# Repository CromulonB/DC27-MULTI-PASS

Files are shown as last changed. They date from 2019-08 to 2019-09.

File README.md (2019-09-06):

# DC27-MULTI-PASS
The MULTI PASS badge is running the firmware created by [badge.team](https://github.com/badgeteam/ESP32-Firmware). It is a unified badge platform that supports running apps written in python. Along with that there is a repository of apps written by other users called the [hatchery](https://badge.team/). The MULTI PASS is compatible with apps written for the SHA and HackerHotel badges.

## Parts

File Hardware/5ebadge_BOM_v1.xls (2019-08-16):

Qty per PCB | Type | Device | Value | Package | Parts
1 | ESP module | ESP32WROOM32 | ESP32-WROOM-32D (16MB) | ESP32MOD | IC3 | x
1 | Touch IC | MPR121QR2 | MPR121QR2 | QFN40P300X300X60-20N | U1 | x
1 | Battery charger IC | TP4056 | TP4056 | SOP-8 | IC4
1 | Voltage regulator | AP2114H-3.3TRG1 | AP2114H-3.3TRG1 | SOT233-3 | IC2 | x
1 | USB-Serial IC | CP210X_USB_UART | CP210X_USB_UART | MLP28 | IC1 | x
1 | Battery connector | JST S3B-PH-SM4-TB | JST S3B-PH-SM4-TB | JST-PH3 | X4 | x
3 | NPN transistor | TRANSISTOR_NPNMMBT2222A | MMBT2222A | SOT23-3 | Q3, Q4, Q6 | x
2 | P-channel MOSFET | MOSFET-PCHANNEL | SSM3J356R,LF | SOT23-3 | T1, T3 | x
1 | N-channel MOSFET | MOSFET-NCHANNEL | 2N7002PW | SOT323 | Q5 | x
2 | Tactile switch | SWITCH-MOMENTARY-2SMD | SKQGABE010 | TACTILE-SWITCH-SMD | S1, S2
1 | USB connector | MOLEX-47346-0001 | 10118192-0001LF | MOLEX-47364-0001 | USB1 | x
1 | IO Expansion header | 610X12243021 | NPPC062KFMS-RC | 610X12243021 | X3 | x
1 | Display socket | 24 pos FPC 0.5mm SMD right angle | 68712414022 | 68712414022 | X1 | x
2 | PTC Fuse | PTCSMD | PTC-1206 1A | PTC-1206 | F1, F2 | x
5 | Schottky diode | BAT20JFILM | NSVR0320MW2T1G | SOD-323 | D2, D3, D7, D8, D9 | x
1 | ESD Suppressor | DIODE-SCHOTTKY-PMEG4005EJ | SD05-7 | SOD-323 | D1 | x
1 | Red LED | LED0603 red | ‎150060RS75000‎ | LED-0603 | D5 | x
1 | Yellow LED | LED0603 yellow | ‎150060YS75000 | LED-0603 | D4 | x
1 | Green LED | LED0603 green | ‎150060VS75000 | LED-0603 | D6 | x
1 | Inductor | INDUCTOR1210 47µ | 445-15771-1-ND (https://www.digikey.com/product-detail/en/tdk-corporation/NLFV32T-470K-EF/445-15771-1-ND/4328067) | L1210 | L1 | x
17 | Capacitor | C0603 100n | CL10B104KB8NNNC (https://www.digikey.com/product-detail/en/samsung-electro-mechanics/CL10B104KB8NNNC/1276-1000-1-ND/3889086) | C0603 | C1, C7, C8, C11, C12, C14, C22, C23, C27, C31, C37, C40, C44, C45, C10, C16, C28, C29 | x
11 | Capacitor | C0603 1µ | CL10B105KA8NNNC (https://www.digikey.com/product-detail/en/samsung-electro-mechanics/CL10B105KA8NNNC/1276-1184-1-ND/3889270) | C0603 | C19, C21, C25, C32, C33, C35, C36, C38, C39, C42, C46 | x
11 | Capacitor | C-EUC0805 4.7µ / 16V | CL21A475KOFNNNE (https://www.digikey.com/product-detail/en/samsung-electro-mechanics/CL21A475KOFNNNE/1276-1065-1-ND/3889151) | C0805 | C9, C15, C17, C18, C20, C24, C26, C30, C34, C41, C43 | x
2 | Resistor | 1.2k | ‎ERJ-3GEYJ122V | R0603 | R29, R35 | x
5 | Resistor | 100k | ERJ-3GEYJ104V | R0603 | R1, R6, R20, R31, R36 | x
12 | Resistor | 10k | ERJ-3GEYJ103V | R0603 | R4, R5, R8, R13, R15, R16, R17, R18, R22, R25, R28, R32 | x
1 | Resistor | 0.27? 1/4W | ERJ-8RQFR27V (https://www.digikey.com/product-detail/en/panasonic-electronic-components/ERJ-8RQFR27V/P.27RCT-ND/250349) | R1206 | R30 | x
3 | Resistor | 1k | ERJ-3GEYJ102V | R0603 | R3, R12, R14 | x
2 | Resistor | 220k | ERJ-3GEYJ224V | R0603 | R7, R21 | x
2 | Resistor | 4k7 | ERJ-PA3J472V (https://www.digikey.com/product-detail/en/panasonic-electronic-components/ERJ-PA3J472V/P4.7KBZCT-ND/5036332) | R0603 | R23, R24 | x
1 | Resistor | 2.7? | ERJ-3GEYJ2R7V (https://www.digikey.com/product-detail/en/panasonic-electronic-components/ERJ-3GEYJ2R7V/P2.7GCT-ND/282415) | R0603 | R19 | x
1 | Resistor | 75k 1% | RMCF0603FT75K0 | R0603 | R37 | x
1 | Micro SD socket | 2908-05WB-MG | 2908-05WB-MG | MICRO-SD-SOCKET-PP | X2 | x
13 | Resistor | R0603 | ERJ-3EKF3000V (https://www.digikey.com/product-detail/en/panasonic-electronic-components/ERJ-3EKF3000V/P300HCT-ND/1746756) | R0603 | R2, R9, R10, R11, R27, R33, R34, R38, R39, R40, R41, R42, R43 | x
1 | MCU | ATMEGA48-20AU | ATMEGA48-20AU | QFP80P900X900X120-32N | U2 | x
2 | JS Slide Switch | slide switch | JS202011SCQN | SW_JS202011SCQN | S3, S4 | x
8 | Topled Yellow Rev.Gul | LED | LY T77K-K2M1-26 | LED_LYT77K-K2M1-26-Z | DY1, DY2, DY3, DY4, DY5, DY6, DY7, DY8 | x
3 | Topled Red Rev.Gul | LED | LS T77K-K1L2-1 | LS T77K-K1L2-1 | DB1, DB2, DB3 | x
126

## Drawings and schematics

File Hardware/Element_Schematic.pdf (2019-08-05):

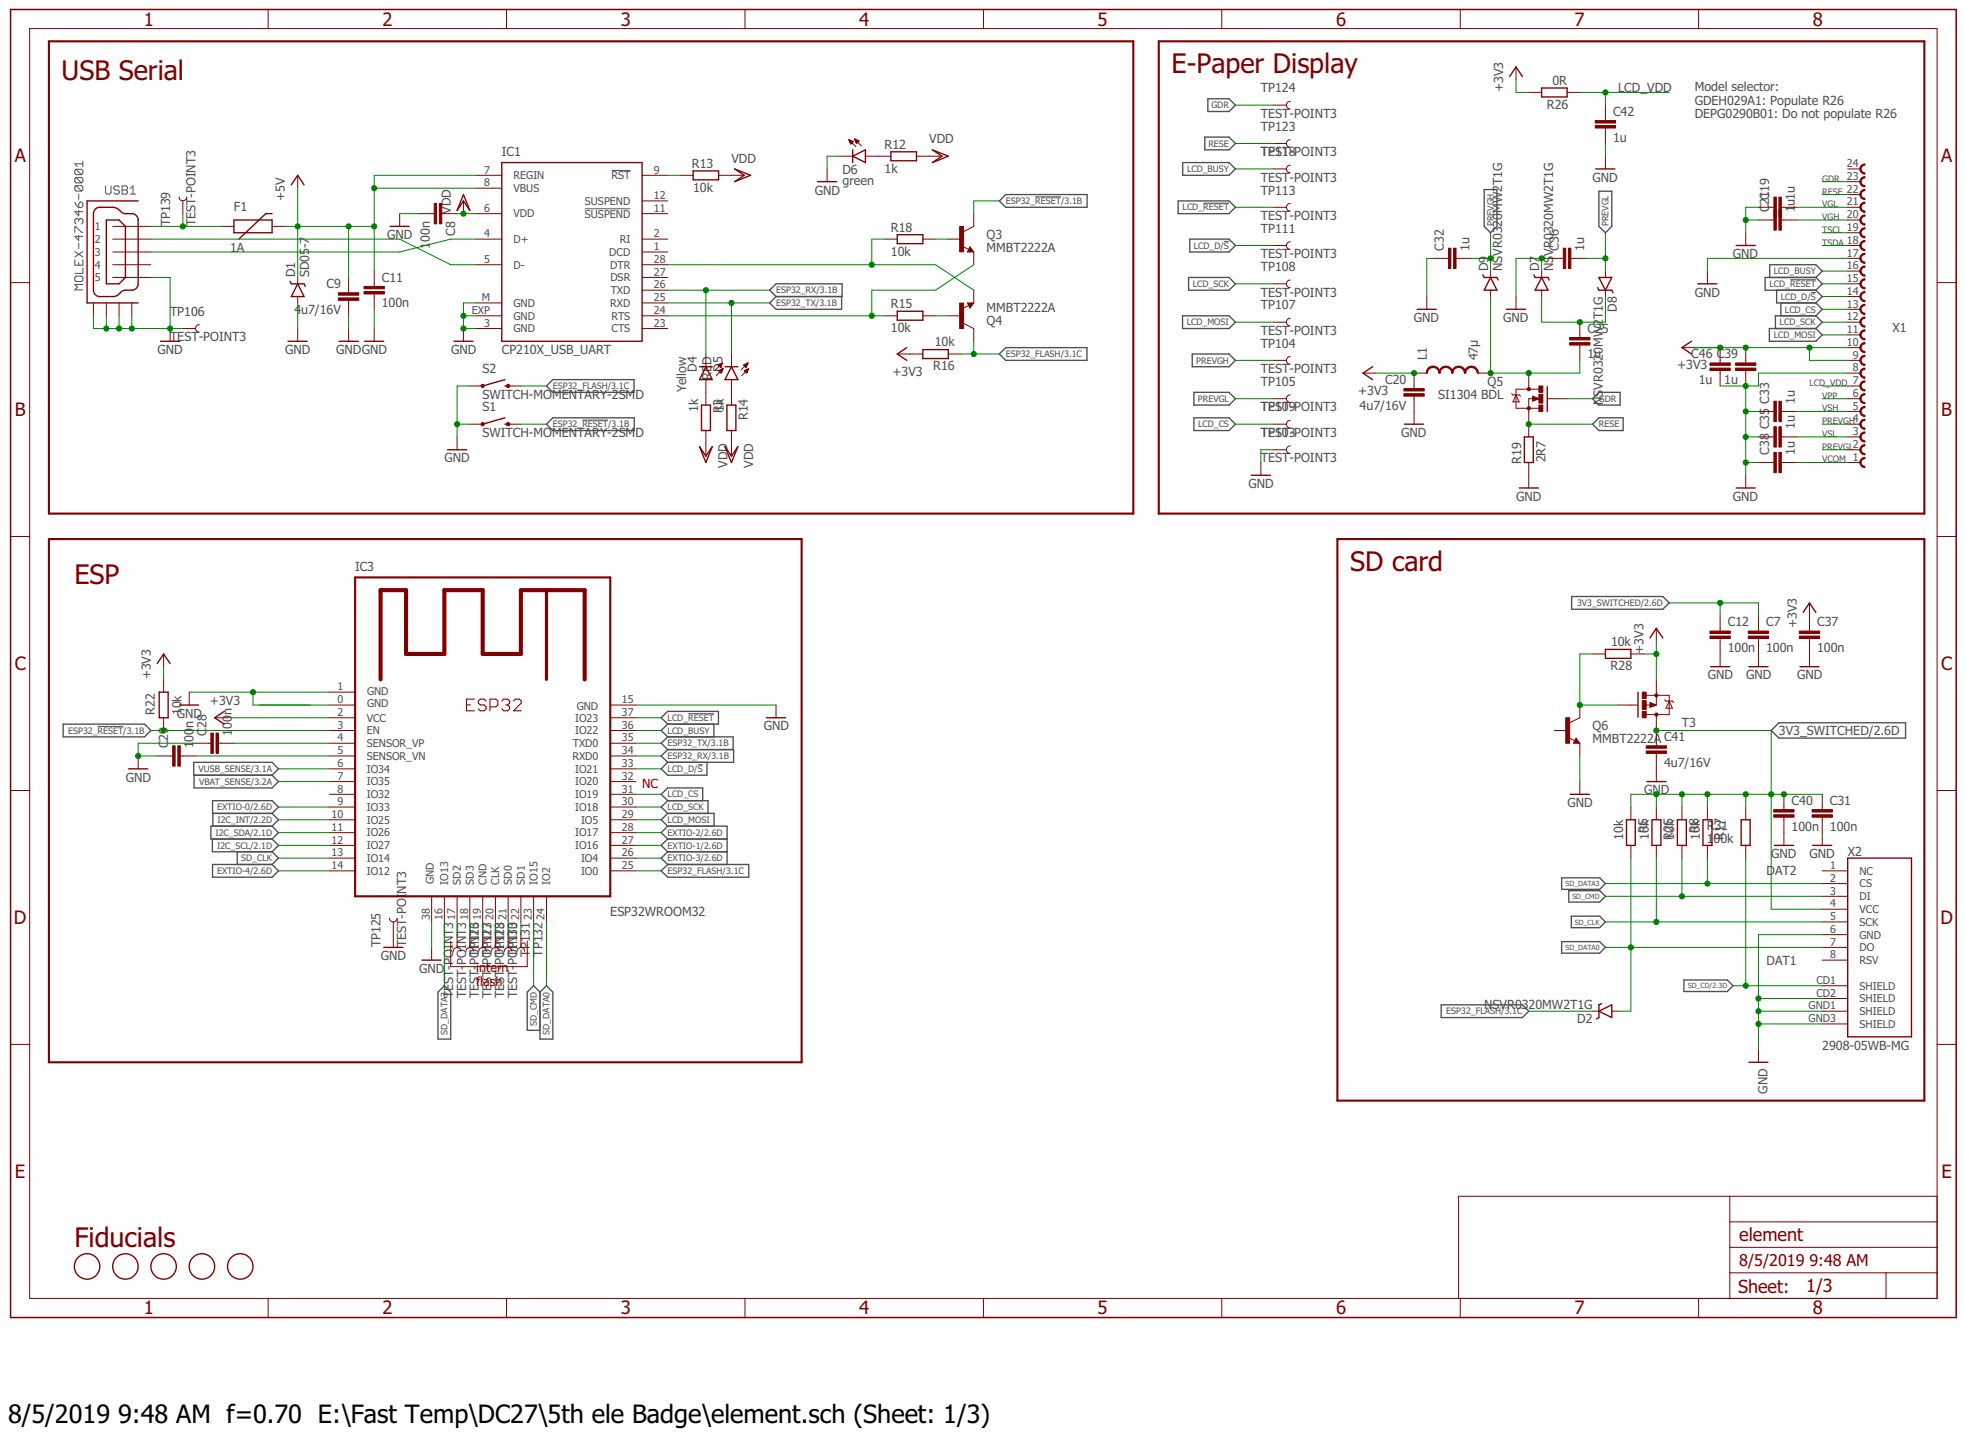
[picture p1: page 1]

TEST-POINT3 TEST-POINT3 TEST-POINT3 TEST-POINT3 TEST-POINT3 TEST-POINT3 TEST-POINT3 TEST-POINT3 TEST-POINT3 TEST-POINT3 TEST-POINT3 GND

Model selector: GDEH029A1: Populate R26 DEPG0290B01: Do not populate R26

TEST-POINT3 TEST-POINT3 TEST-POINT3 TEST-POINT3 TEST-POINT3 TEST-POINT3 TEST-POINT3 GND

8/5/2019 9:48 AM f=0.70 E:\Fast Temp\DC27\5th ele Badge\element.sch (Sheet: 1/3)

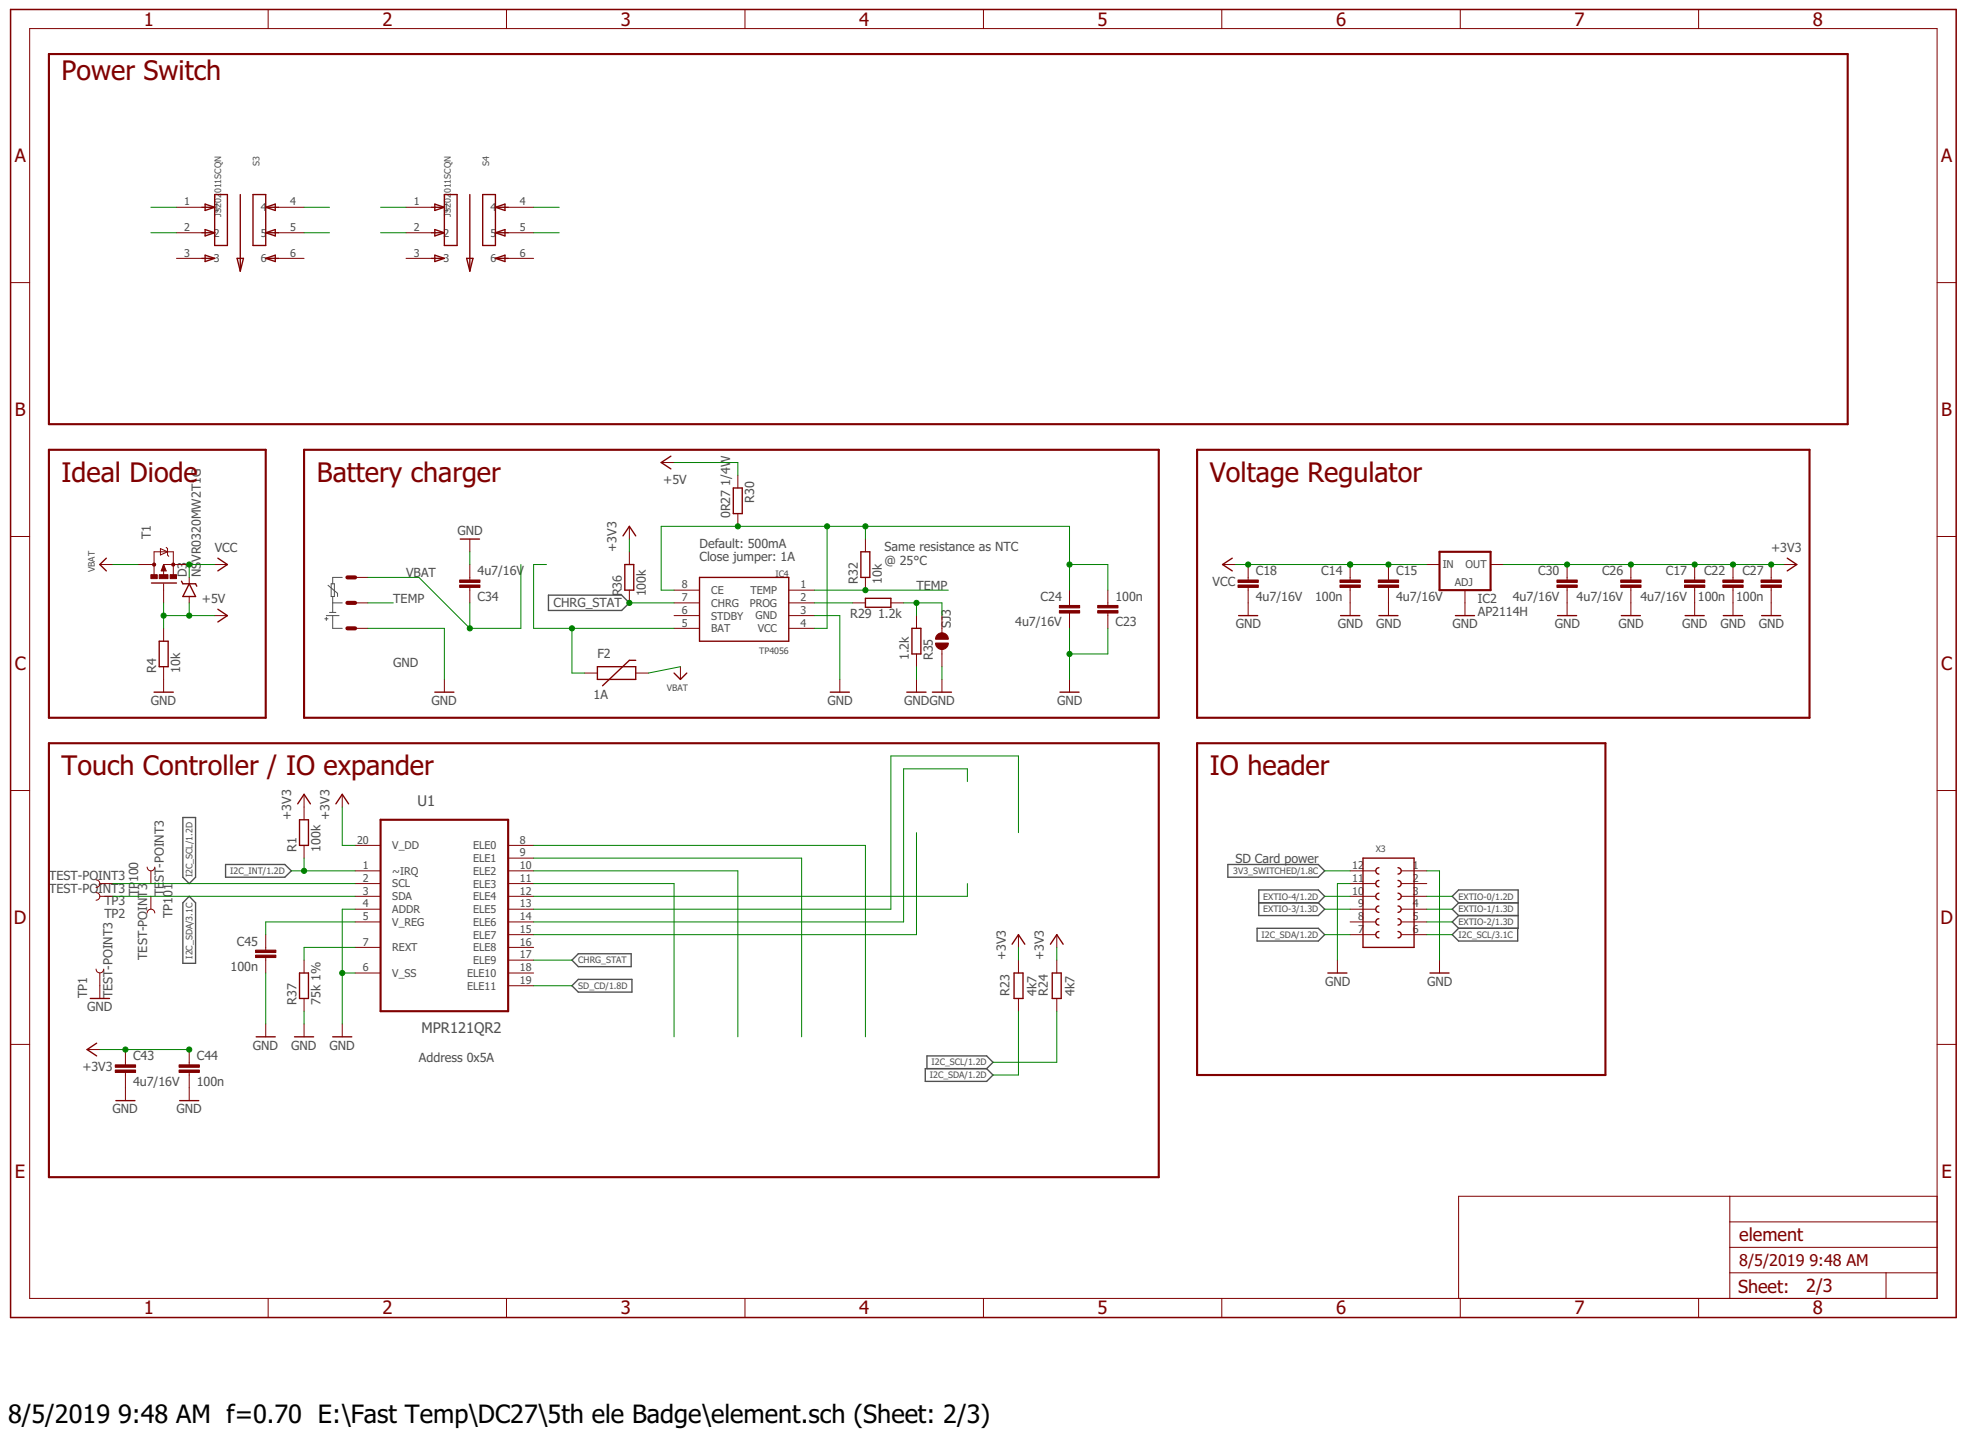
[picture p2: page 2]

Same resistance as NTC @ 25°C

11 ELE4

13 ELE6

8/5/2019 9:48 AM f=0.70 E:\Fast Temp\DC27\5th ele Badge\element.sch (Sheet: 2/3)

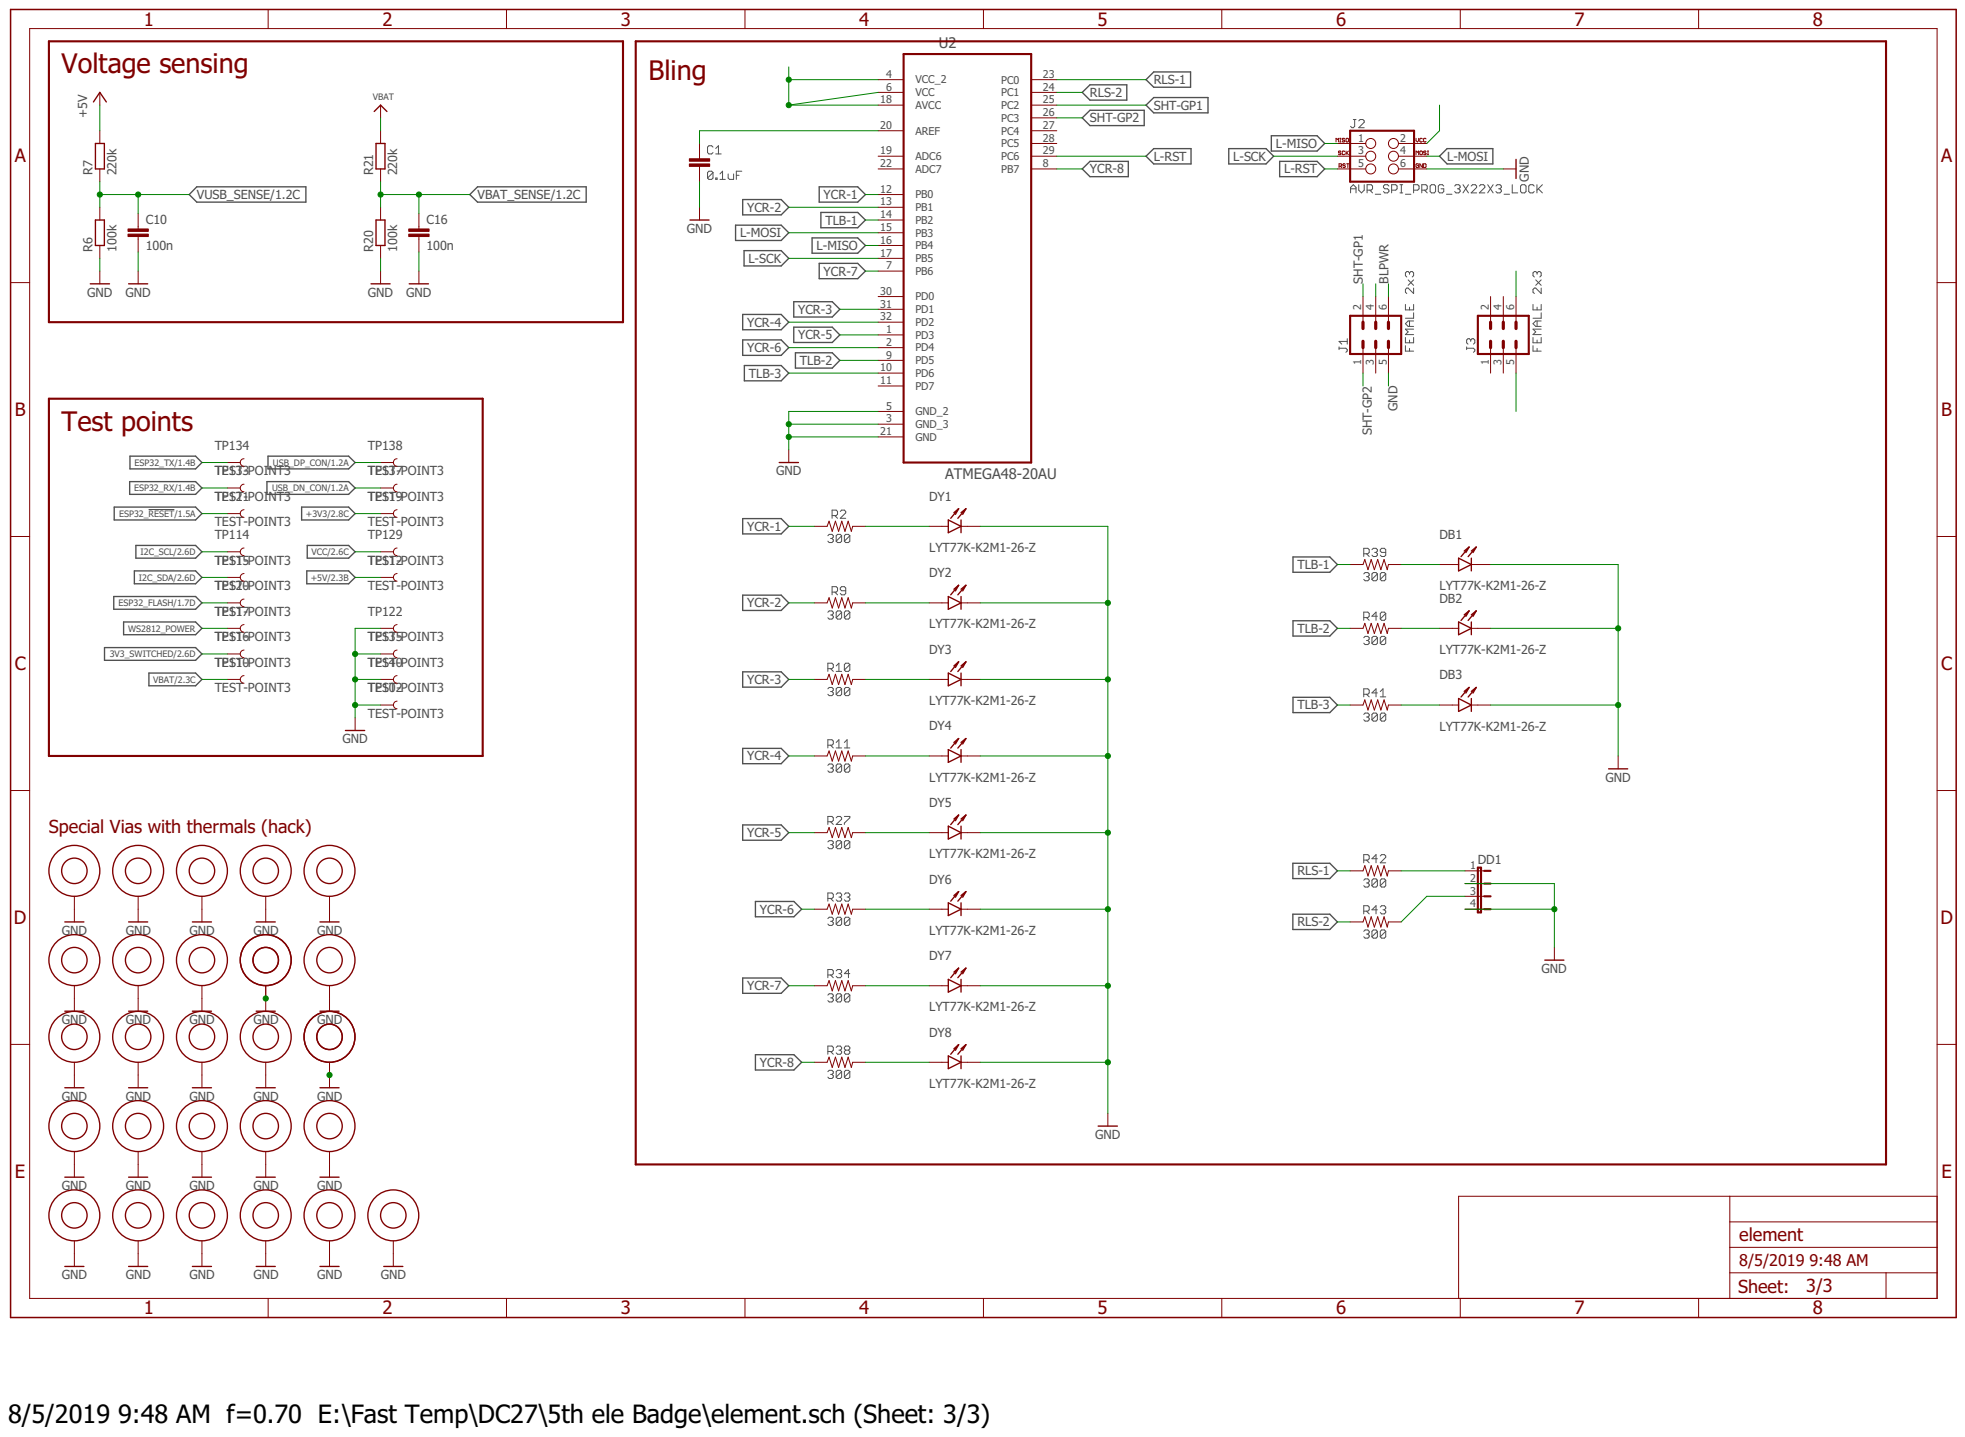
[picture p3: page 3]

Test points
TEST-POINT3 TEST-POINT3 TEST-POINT3 TEST-POINT3 GND

Special Vias with thermals (hack)

8/5/2019 9:48 AM f=0.70 E:\Fast Temp\DC27\5th ele Badge\element.sch (Sheet: 3/3)

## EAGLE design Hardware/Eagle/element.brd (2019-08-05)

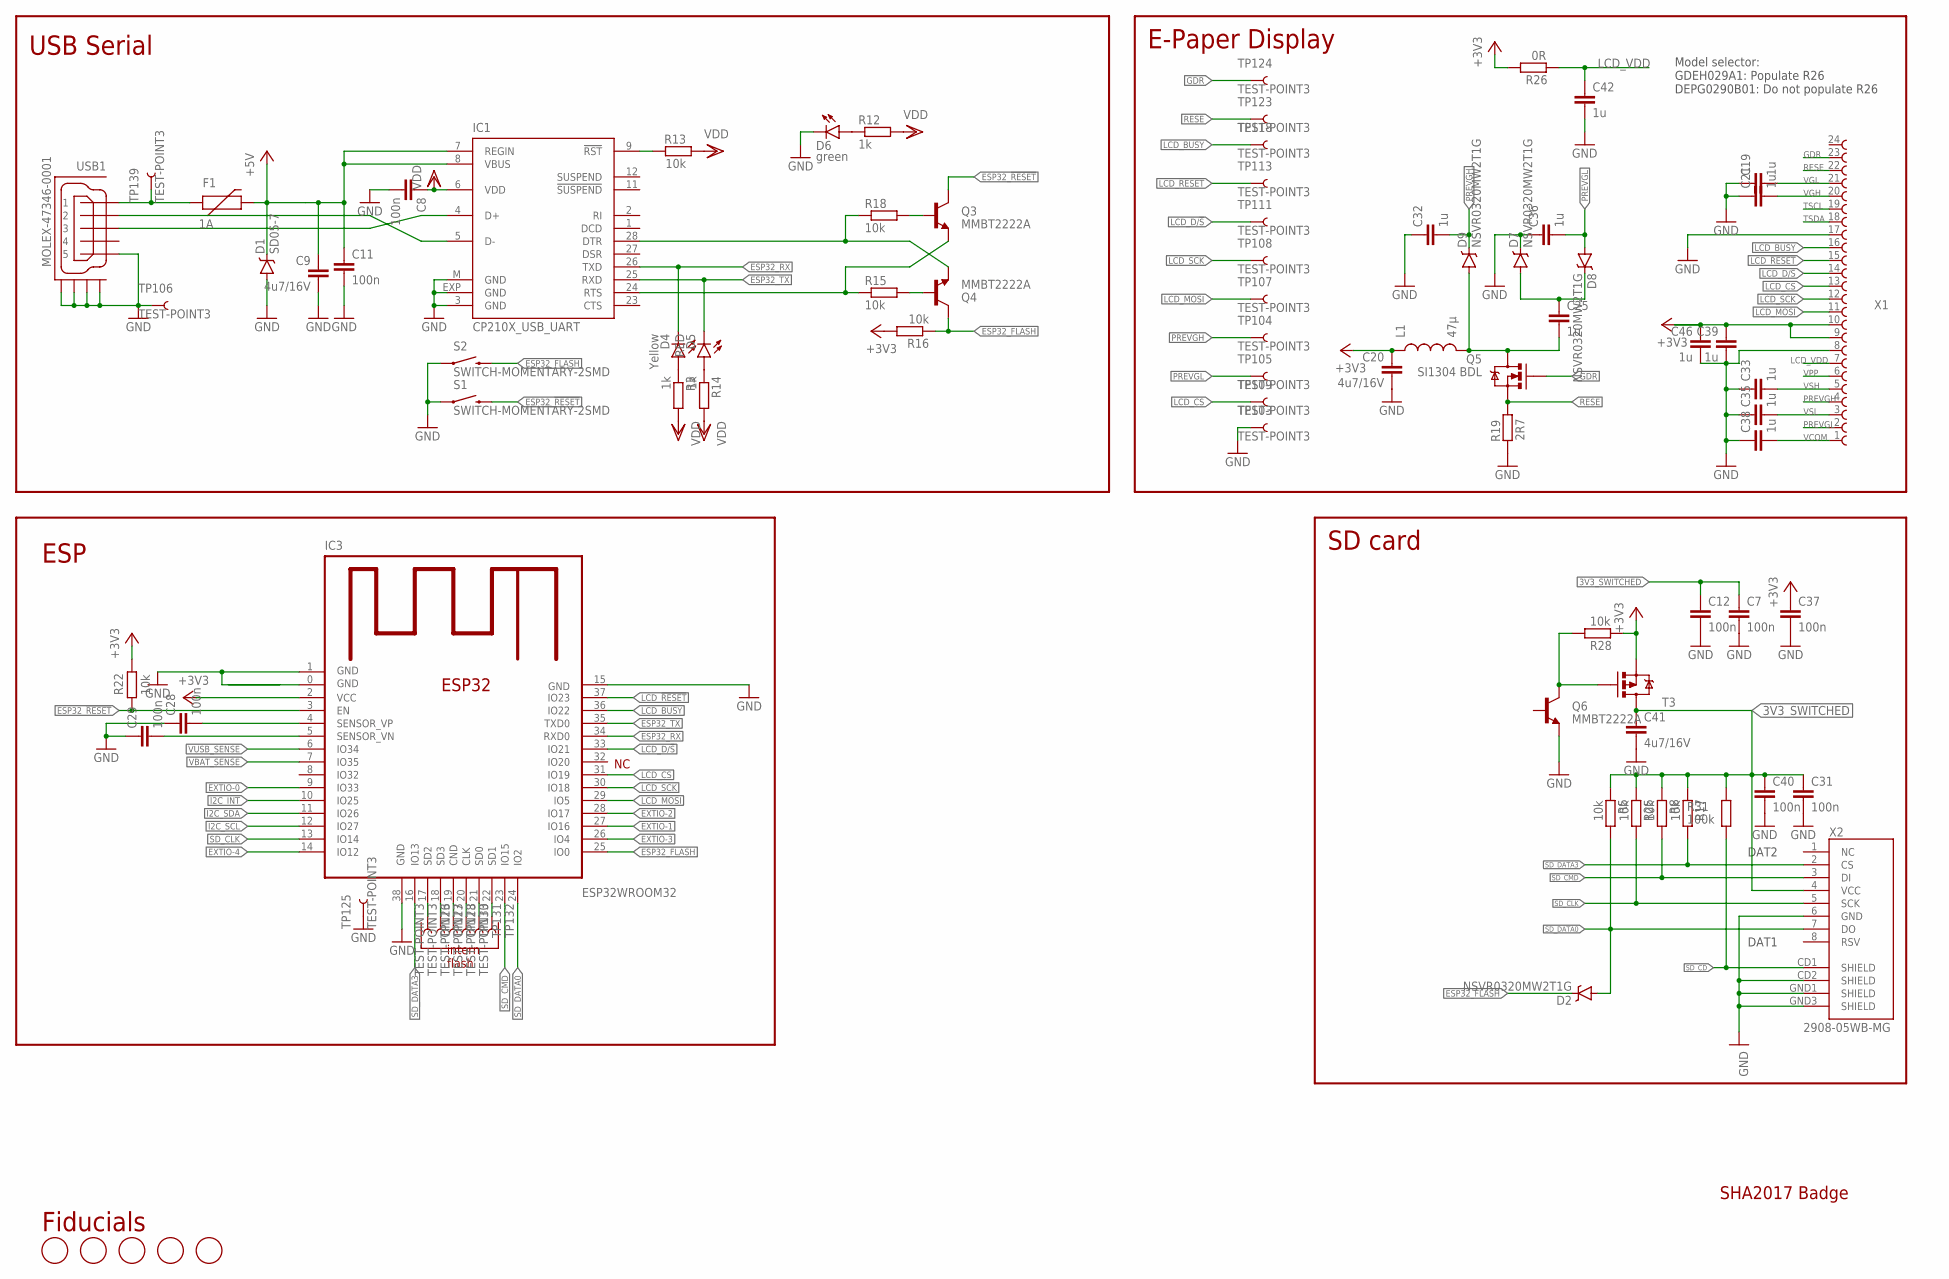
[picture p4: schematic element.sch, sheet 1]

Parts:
C7, C8, C11, C12, C28, C29, C31, C37, C40: 100n; C0603-DASHES; PARTNO GRM188R71H104KA93D
C9, C20, C41: 4u7/16V; C0805; PARTNO GRM21BR61C475KA88K
C19, C21, C25, C32, C33, C35, C36, C38, C39, C42, C46: 1u; C0603-DASHES; PARTNO GRM188R61E105KA12D
D1: SD05-7; SOD-323; PARTNO SD05-7
D2, D7, D8, D9: NSVR0320MW2T1G; SOD-323; PARTNO BAT20JFILM
D4: Yellow; LED-0603
D5: RED; LED-0603
D6: green; LED-0603
F1: 1A; PTC-1206
FD1, FD2, FD3, FD4, FD5: FIDUCIAL; FIDUCIAL_1MM; PARTNO NAP
IC1: CP210X_USB_UART; MLP28; PARTNO CP2102-GMR
IC3: ESP32WROOM32; ESP32MOD
L1: 47µ; 1210; PARTNO NLCV32T-220K-EF
Q3, Q4, Q6: MMBT2222A; SOT23-3; PARTNO BC817-25,215
Q5: SI1304 BDL; SOT323; PARTNO SI1308EDL-T1-GE3
R3, R12, R14: 1k; R0603-DASHES; PARTNO ERJ-3GEYJ102V
R5, R8, R13, R15, R16, R17, R18, R22, R25, R28: 10k; R0603-DASHES; PARTNO ERJ-3GEYJ103V
R19: 2R7; R0603-DASHES; PARTNO ERJ-3GEYJ5R1V
R26: 0R; R0603-DASHES; PARTNO ERJ-3GEYJ5R1V
R31: 100k; R0603-DASHES; PARTNO ERJ-3GEYJ104V
S1, S2: SWITCH-MOMENTARY-2SMD; TACTILE-SWITCH-SMD; PARTNO SKQGABE010
T3: MOSFET-PCHANNEL; SOT23-3
TP103, TP104, TP105, TP106, TP107, TP108, TP109, TP111, TP113, TP118, TP123, TP124, TP125, TP126, TP127, TP128, TP130, TP131, TP132, TP139: TEST-POINT3; PAD.03X.03; PARTNO NAP
USB1: MOLEX-47346-0001; MOLEX-47364-0001; PARTNO 10118192-0001LF
X1: 68712414022; PARTNO 68712414022
X2: 2908-05WB-MG; MICRO-SD-SOCKET-PP; PARTNO 2908-05WB-MG

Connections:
3V3_SWITCHED: C7.1, C12.1, C31.1, C40.1, C41.1, R5.2, R8.2, R17.2, R25.2, R31.1, T3.3 (D), X2.4 (VCC); also elsewhere on the board
+3V3: C20.1, C37.1, C39.1, C46.1, IC3.2 (VCC), L1.1, R16.2, R22.1, R26.1, R28.2, T3.2 (S), X1.9, X1.10; also elsewhere on the board
+5V: C9.1, C11.1, D1.C, F1.2, IC1.7 (REGIN), IC1.8 (VBUS); also elsewhere on the board
CD0: IC3.21 (SD0), TP131.P$1
CLK: IC3.20 (CLK), TP130.P$1
CND: IC3.19 (CND), TP128.P$1
ESP32_!RESET: IC3.3 (EN), Q3.3 (C), R22.2, S1.3 (2); also elsewhere on the board
ESP32_FLASH: D2.C, IC3.25 (IO0), Q4.3 (C), R16.1, S2.3 (2); also elsewhere on the board
ESP32_RX: D4.C, IC1.26 (TXD), IC3.34 (RXD0); also elsewhere on the board
ESP32_TX: D5.C, IC1.25 (RXD), IC3.35 (TXD0); also elsewhere on the board
EXTIO-0: IC3.9 (IO33); also elsewhere on the board
EXTIO-1: IC3.27 (IO16); also elsewhere on the board
EXTIO-2: IC3.28 (IO17); also elsewhere on the board
EXTIO-3: IC3.26 (IO4); also elsewhere on the board
EXTIO-4: IC3.14 (IO12); also elsewhere on the board
GDR: Q5.1 (G), TP124.P$1, X1.23
GND: C7.2, C8.2, C9.2, C11.2, C12.2, C19.1, C20.2, C21.1, C28.1, C29.1, C31.2, C32.1, C33.1, C35.1, C36.1, C37.2, C38.1, C39.2, C40.2, C41.2, C42.2, C46.2, D1.A, D6.C, D7.C, IC1.3 (GND), IC1.EXP (GND), IC1.M (GND), IC3.0 (GND), IC3.1 (GND), IC3.15 (GND), IC3.38 (GND), Q6.2 (E), R19.2, S1.1, S2.1, TP103.P$1, TP106.P$1, TP125.P$1, USB1.5, USB1.GND1, USB1.GND2, USB1.GND3, USB1.GND4, X1.8, X1.17, X2.6 (GND), X2.CD2 (SHIELD), X2.GND1 (SHIELD), X2.GND3 (SHIELD); also elsewhere on the board
I2C_INT: IC3.10 (IO25); also elsewhere on the board
I2C_SCL: IC3.12 (IO27); also elsewhere on the board
I2C_SDA: IC3.11 (IO26); also elsewhere on the board
LCD_!RESET: IC3.37 (IO23), TP113.P$1, X1.15
LCD_BUSY: IC3.36 (IO22), TP118.P$1, X1.16
LCD_CS: IC3.31 (IO19), TP109.P$1, X1.13
LCD_D/!S: IC3.33 (IO21), TP111.P$1, X1.14
LCD_MOSI: IC3.29 (IO5), TP107.P$1, X1.11
LCD_SCK: IC3.30 (IO18), TP108.P$1, X1.12
LCD_VDD: C42.1, R26.2, X1.7
unnamed: IC1.9 (!RST), R13.2
unnamed: IC1.24 (RTS), Q3.2 (E), R15.1
unnamed: IC1.28 (DTR), Q4.2 (E), R18.1
unnamed: Q4.1 (B), R15.2
unnamed: Q3.1 (B), R18.2
unnamed: Q6.3 (C), R28.1, T3.1 (G)
unnamed: C25.1, D7.A, D8.C
unnamed: C25.2, D9.A, L1.2, Q5.3 (D)
unnamed: D6.A, R12.1
unnamed: D4.A, R3.1
unnamed: D5.A, R14.1
unnamed: F1.1, TP139.P$1, USB1.1
unnamed: C28.2, IC3.4 (SENSOR_VP)
unnamed: C29.2, IC3.5 (SENSOR_VN)
PREVGH: C32.2, D9.C, TP104.P$1, X1.4
PREVGL: C36.2, D8.A, TP105.P$1, X1.2
RESE: Q5.2 (S), R19.1, TP123.P$1, X1.22
SD1: IC3.22 (SD1), TP132.P$1
SD2: IC3.17 (SD2), TP126.P$1
SD3: IC3.18 (SD3), TP127.P$1
SD_CD: R31.2, X2.CD1 (SHIELD); also elsewhere on the board
SD_CLK: IC3.13 (IO14), R25.1, X2.5 (SCK)
SD_CMD: IC3.23 (IO15), R8.1, X2.3 (DI)
SD_DATA0: D2.A, IC3.24 (IO2), R5.1, X2.7 (DO)
SD_DATA3: IC3.16 (IO13), R17.1, X2.2 (CS)
TSCL: X1.19
TSDA: X1.18
USB_DN_CON: IC1.5 (D-), USB1.2; also elsewhere on the board
USB_DP_CON: IC1.4 (D+), USB1.3; also elsewhere on the board
VBAT_SENSE: IC3.7 (IO35); also elsewhere on the board
VCOM: C38.2, X1.1
VDD: C8.1, IC1.6 (VDD), R3.2, R12.2, R13.1, R14.2
VGH: C21.2, X1.20
VGL: C19.2, X1.21
VPP: X1.6
VSH: C33.2, X1.5
VSL: C35.2, X1.3
VUSB_SENSE: IC3.6 (IO34); also elsewhere on the board

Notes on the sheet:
USB Serial
E-Paper Display
SD card
intern flash
ESP
Fiducials
DAT1
DAT2
Model selector: GDEH029A1: Populate R26 DEPG0290B01: Do not populate R26
SHA2017 Badge

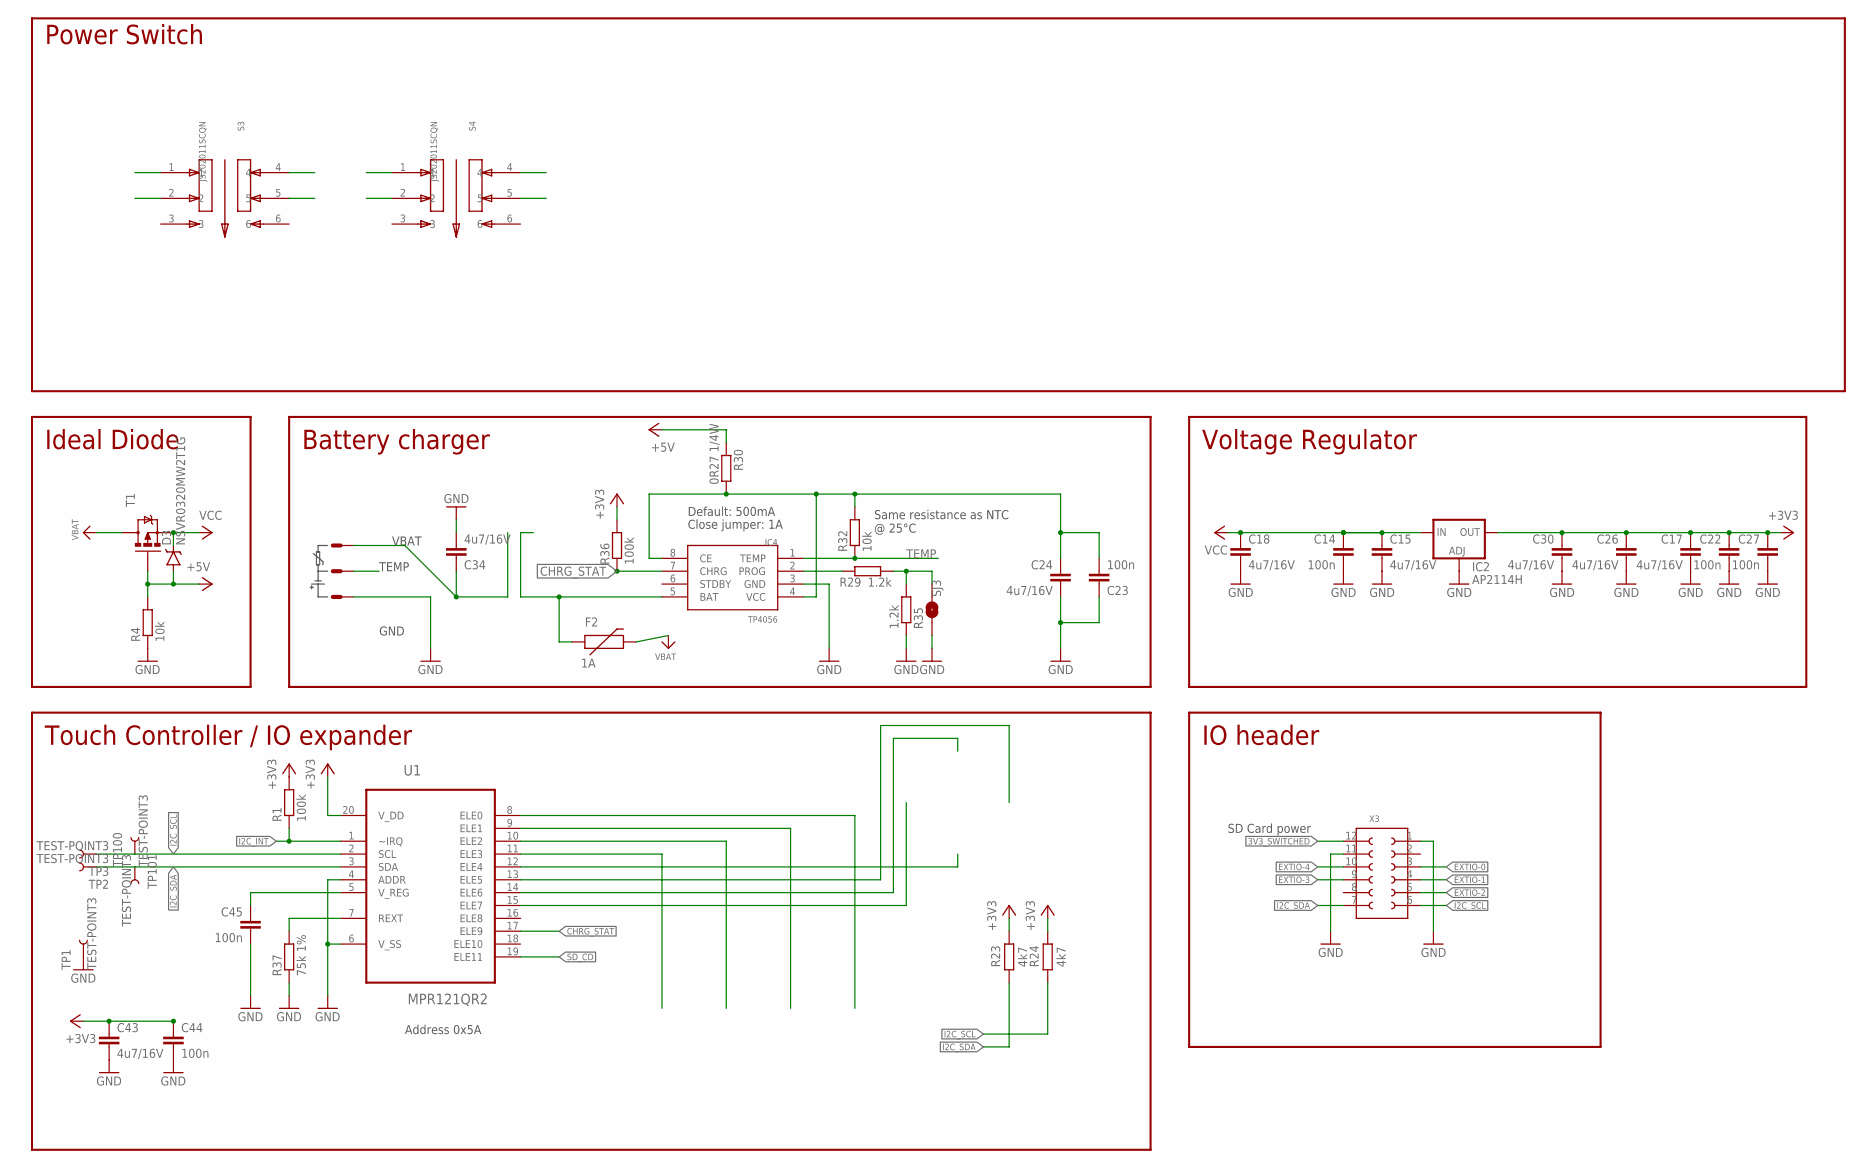
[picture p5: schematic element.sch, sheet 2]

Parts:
C14, C22, C23, C27, C44, C45: 100n; C0603-DASHES; PARTNO GRM188R71H104KA93D
C15, C17, C18, C24, C26, C30, C34, C43: 4u7/16V; C0805; PARTNO GRM21BR61C475KA88K
D3: NSVR0320MW2T1G; SOD-323; PARTNO BAT20JFILM
F2: 1A; PTC-1206
IC2: AP2114H; SOT223; PARTNO AP7215-33YG-13
IC4: TP4056; SOP-8
R1, R36: 100k; R0603-DASHES; PARTNO ERJ-3GEYJ104V
R4: 10k; R0603-DASHES; PARTNO ERJ-3GEYJ103V
R23, R24: 4k7; R0603-DASHES; PARTNO ERJ-3GEYJ103V
R29, R35: 1.2k; R0603-DASHES; PARTNO ERJ-3GEYJ222V
R30: 0R27 1/4W; R1206; PARTNO ERJ-3GEYJ154V
R32: 10k; R0603-DASHES; PARTNO ERJ-3GEYJ154V
R37: 75k 1%; R0603-DASHES; PARTNO ERJ-3GEYJ104V
S3, S4: JS202011SCQN; SW_JS202011SCQN
SJ3: JUMPER-PAD-2-NOYES_SILK; PAD-JUMPER-2-NO_YES_SILK; PARTNO NAP
T1: MOSFET-PCHANNEL; SOT23-3
TP1, TP2, TP3, TP100, TP101: TEST-POINT3; PAD.03X.03; PARTNO NAP
U1: MPR121QR2; QFN40P300X300X60-20N
X3: 610X12243021; PARTNO 517-153208-2020-TB
X4: JST-PH3

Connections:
3V3_SWITCHED: X3.12 (1); also elsewhere on the board
+3V3: C17.1, C22.1, C26.1, C27.1, C30.1, C43.1, C44.1, IC2.4 (OUT), R1.2, R23.1, R24.1, R36.2, U1.20 (V_DD); also elsewhere on the board
+5V: D3.A, R4.2, R30.1, T1.1 (G); also elsewhere on the board
BLPWR: S4.1, S4.4; also elsewhere on the board
CHRG_STAT: IC4.7 (CHRG), R36.1, U1.17 (ELE9)
EXTIO-0: X3.3 (10); also elsewhere on the board
EXTIO-1: X3.4 (9); also elsewhere on the board
EXTIO-2: X3.5 (8); also elsewhere on the board
EXTIO-3: X3.9 (4); also elsewhere on the board
EXTIO-4: X3.10 (3); also elsewhere on the board
GND: C14.2, C15.2, C17.2, C18.2, C22.2, C23.1, C24.2, C26.2, C27.2, C30.2, C34.2, C43.2, C44.2, C45.2, IC2.1 (ADJ), IC4.3 (GND), R4.1, R35.2, R37.1, SJ3.1, TP1.P$1, U1.4 (ADDR), U1.6 (V_SS), X3.1 (12), X3.11 (2), X4.3; also elsewhere on the board
I2C_INT: R1.1, U1.1 (~IRQ); also elsewhere on the board
I2C_SCL: R24.2, TP3.P$1, TP100.P$1, U1.2 (SCL), X3.6 (7); also elsewhere on the board
I2C_SDA: R23.2, TP2.P$1, TP101.P$1, U1.3 (SDA), X3.7 (6); also elsewhere on the board
unnamed: IC4.2 (PROG), R29.1
unnamed: R29.2, R35.1, SJ3.2
unnamed: C23.2, C24.1, IC4.4 (VCC), IC4.8 (CE), R30.2, R32.2
unnamed: C45.1, U1.5 (V_REG)
unnamed: R37.2, U1.7 (REXT)
unnamed: F2.1, IC4.5 (BAT), S3.1, S3.4
SD_CD: U1.19 (ELE11); also elsewhere on the board
SWBDG: C34.1, S3.2, S3.5, S4.2, S4.5, X4.1
TEMP: IC4.1 (TEMP), R32.1, X4.2
VBAT: F2.2, T1.3 (D); also elsewhere on the board
VCC: C14.1, C15.1, C18.1, D3.C, IC2.3 (IN), T1.2 (S); also elsewhere on the board

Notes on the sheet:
Voltage Regulator
Battery charger
Ideal Diode
Default: 500mA
Close jumper: 1A
GND
VBAT
Same resistance as NTC @ 25°C
Touch Controller / IO expander
Address 0x5A
IO header
SD Card power
Power Switch
TEMP

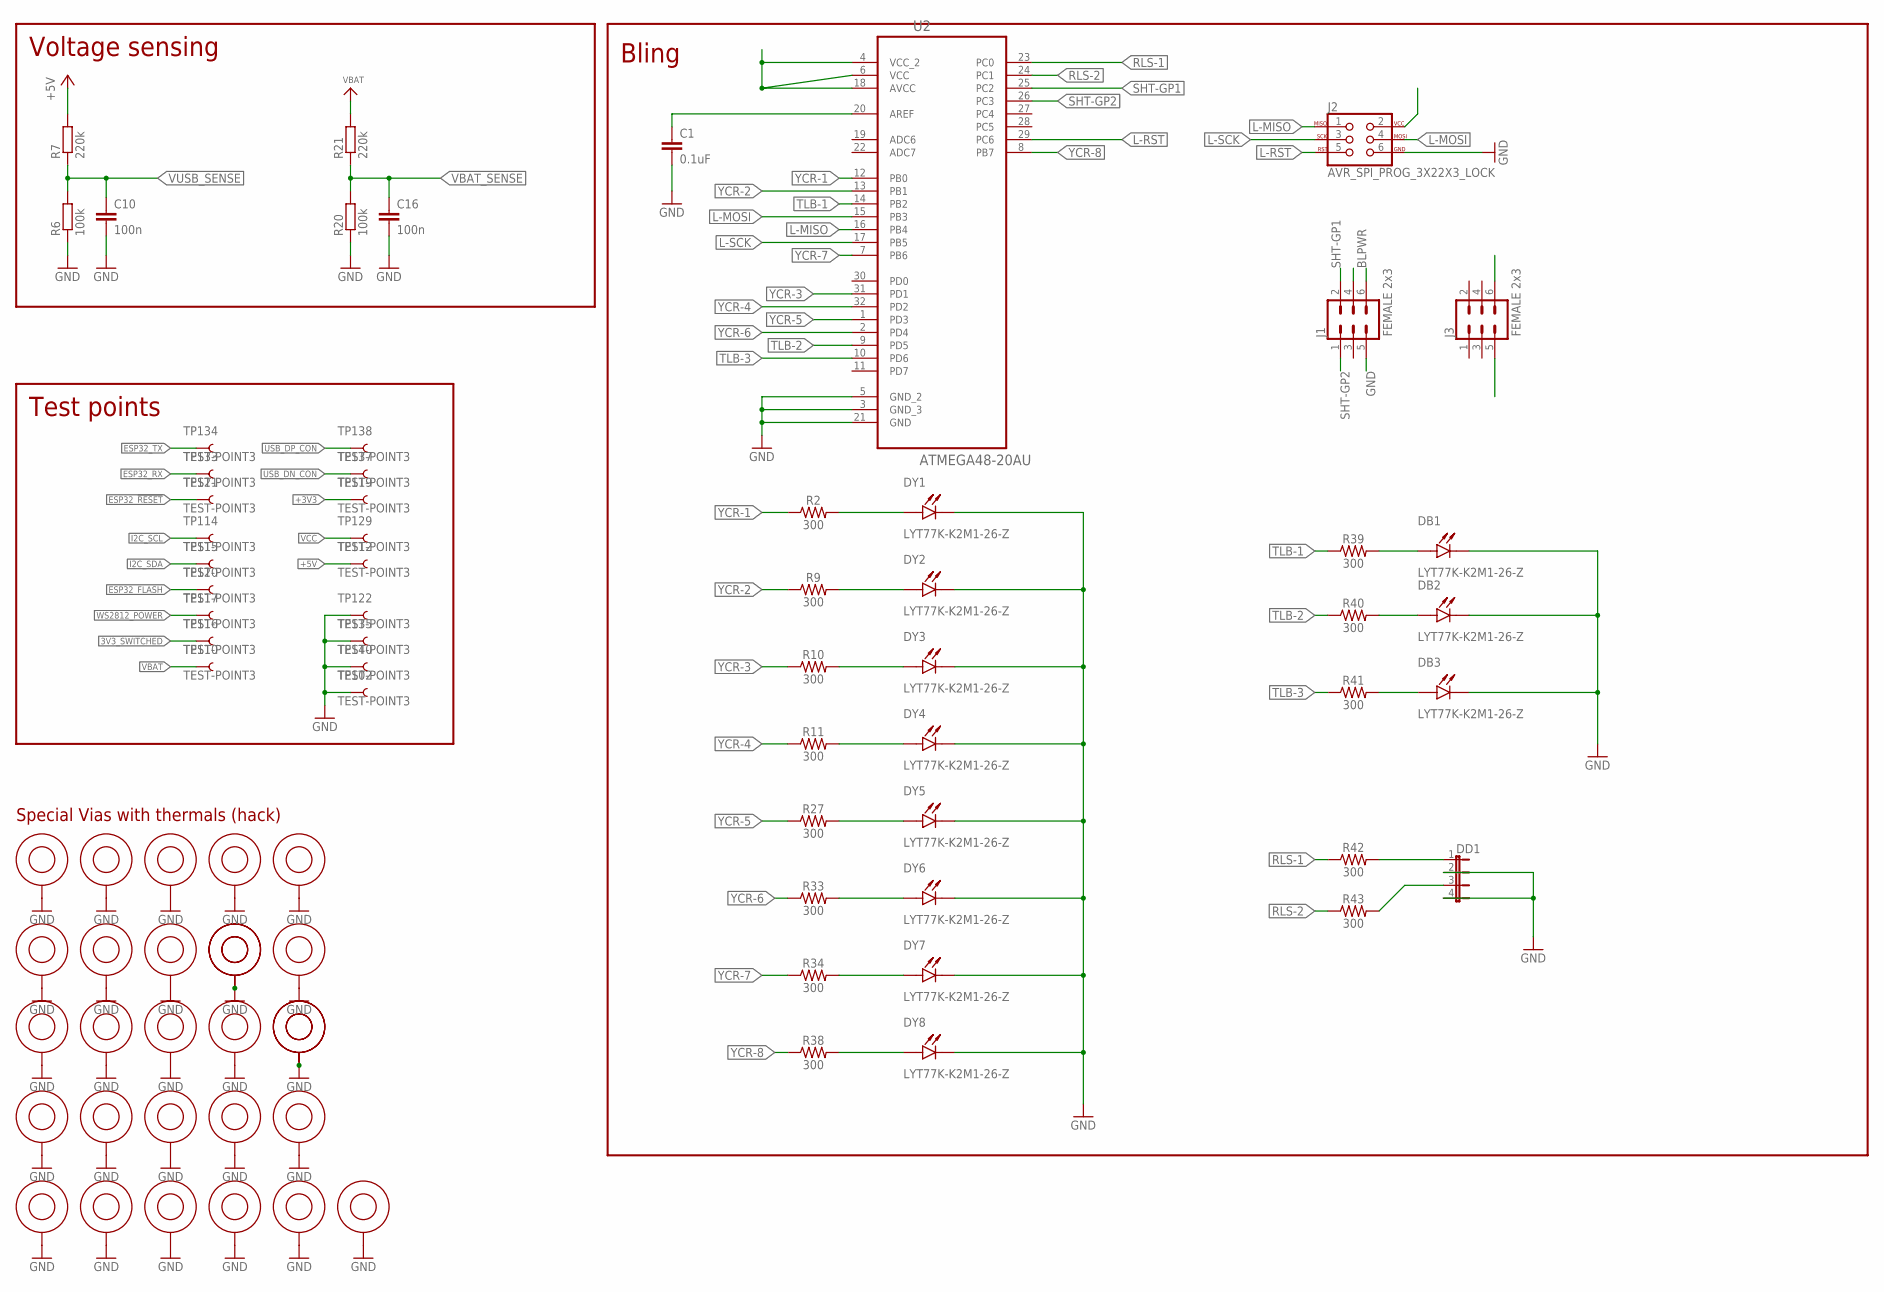
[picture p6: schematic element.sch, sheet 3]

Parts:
$$U$1, $$U$2, $$U$3, $$U$4, $$U$5, $$U$6, $$U$7, $$U$8, $$U$9: VIA; PARTNO NAP
C1: 0.1uF; 0603
C10, C16: 100n; C0603-DASHES; PARTNO GRM188R71H104KA93D
DB1, DB2, DB3: LYT77K-K2M1-26-Z; LED_LYT77K-K2M1-26-Z
DD1: JP4E; JP4
DY1, DY2, DY3, DY4, DY5, DY6, DY7, DY8: LYT77K-K2M1-26-Z; LED_LYT77K-K2M1-26-Z
J1, J3: FEMALE 2x3; 2X3
J2: AVR_SPI_PROG_3X22X3_LOCK; 2X3_LOCK
R2, R9, R10, R11, R27, R33, R34, R38, R39, R40, R41, R42, R43: 300; 0603
R6, R20: 100k; R0603-DASHES; PARTNO ERJ-3GEYJ104V
R7, R21: 220k; R0603-DASHES; PARTNO ERJ-3GEYJ224V
TP102, TP110, TP112, TP114, TP115, TP116, TP117, TP119, TP120, TP121, TP122, TP129, TP133, TP134, TP135, TP137, TP138, TP140: TEST-POINT3; PAD.03X.03; PARTNO NAP
U2: ATMEGA48-20AU; QFP80P900X900X120-32N
U$2, U$3, U$4, U$5, U$6, U$10, U$11, U$12, U$13, U$14, U$15, U$16, U$17, U$18, U$19, U$20, U$21, U$22, U$23: VIA; PARTNO NAP

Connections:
3V3_SWITCHED: TP116.P$1; also elsewhere on the board
+3V3: TP119.P$1; also elsewhere on the board
+5V: R7.2, TP112.P$1; also elsewhere on the board
BLPWR: J1.6, J2.2, J3.6, U2.4 (VCC_2), U2.6 (VCC), U2.18 (AVCC); also elsewhere on the board
ESP32_!RESET: TP121.P$1; also elsewhere on the board
ESP32_FLASH: TP120.P$1; also elsewhere on the board
ESP32_RX: TP133.P$1; also elsewhere on the board
ESP32_TX: TP134.P$1; also elsewhere on the board
GND: $$U$1.P$1, $$U$2.P$1, $$U$3.P$1, $$U$4.P$1, $$U$5.P$1, $$U$6.P$1, $$U$7.P$1, $$U$8.P$1, $$U$9.P$1, C1.2, C10.2, C16.2, DB1.1 (C), DB2.1 (C), DB3.1 (C), DD1.2, DD1.4, DY1.1 (C), DY2.1 (C), DY3.1 (C), DY4.1 (C), DY5.1 (C), DY6.1 (C), DY7.1 (C), DY8.1 (C), J1.5, J2.6, J3.5, R6.1, R20.1, TP102.P$1, TP122.P$1, TP135.P$1, TP140.P$1, U2.3 (GND_3), U2.5 (GND_2), U2.21 (GND), U$2.P$1, U$3.P$1, U$4.P$1, U$5.P$1, U$6.P$1, U$10.P$1, U$11.P$1, U$12.P$1, U$13.P$1, U$14.P$1, U$15.P$1, U$16.P$1, U$17.P$1, U$18.P$1, U$19.P$1, U$20.P$1, U$21.P$1, U$22.P$1, U$23.P$1; also elsewhere on the board
I2C_SCL: TP114.P$1; also elsewhere on the board
I2C_SDA: TP115.P$1; also elsewhere on the board
L-MISO: J2.1, U2.16 (PB4)
L-MOSI: J2.4, U2.15 (PB3)
L-RST: J2.5, U2.29 (PC6)
L-SCK: J2.3, U2.17 (PB5)
unnamed: DY1.2 (A), R2.2
unnamed: DY2.2 (A), R9.2
unnamed: DY3.2 (A), R10.2
unnamed: DY4.2 (A), R11.2
unnamed: DY5.2 (A), R27.2
unnamed: DY6.2 (A), R33.2
unnamed: DY7.2 (A), R34.2
unnamed: DY8.2 (A), R38.2
unnamed: DD1.1, R42.2
unnamed: DD1.3, R43.2
unnamed: DB1.2 (A), R39.2
unnamed: DB2.2 (A), R40.2
unnamed: DB3.2 (A), R41.2
unnamed: C1.1, U2.20 (AREF)
RLS-1: R42.1, U2.23 (PC0)
RLS-2: R43.1, U2.24 (PC1)
SHT-GP1: J1.2, U2.25 (PC2)
SHT-GP2: J1.1, U2.26 (PC3)
TLB-1: R39.1, U2.14 (PB2)
TLB-2: R40.1, U2.9 (PD5)
TLB-3: R41.1, U2.10 (PD6)
USB_DN_CON: TP137.P$1; also elsewhere on the board
USB_DP_CON: TP138.P$1; also elsewhere on the board
VBAT: R21.2, TP110.P$1; also elsewhere on the board
VBAT_SENSE: C16.1, R20.2, R21.1; also elsewhere on the board
VCC: TP129.P$1; also elsewhere on the board
VUSB_SENSE: C10.1, R6.2, R7.1; also elsewhere on the board
WS2812_POWER: TP117.P$1
YCR-1: R2.1, U2.12 (PB0)
YCR-2: R9.1, U2.13 (PB1)
YCR-3: R10.1, U2.31 (PD1)
YCR-4: R11.1, U2.32 (PD2)
YCR-5: R27.1, U2.1 (PD3)
YCR-6: R33.1, U2.2 (PD4)
YCR-7: R34.1, U2.7 (PB6)
YCR-8: R38.1, U2.8 (PB7)

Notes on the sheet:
Special Vias with thermals (hack)
Test points
Voltage sensing
Bling

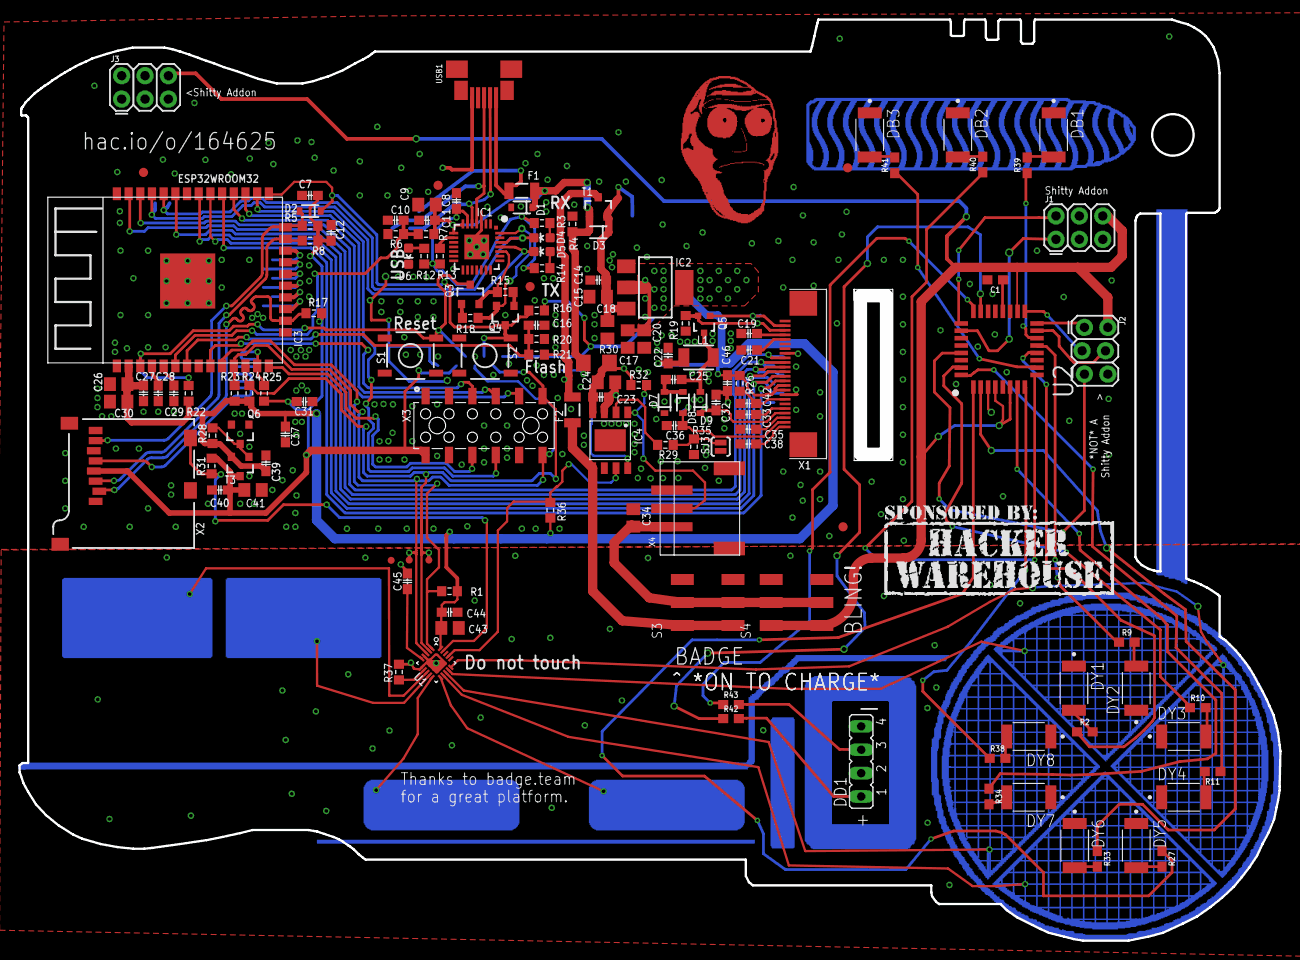
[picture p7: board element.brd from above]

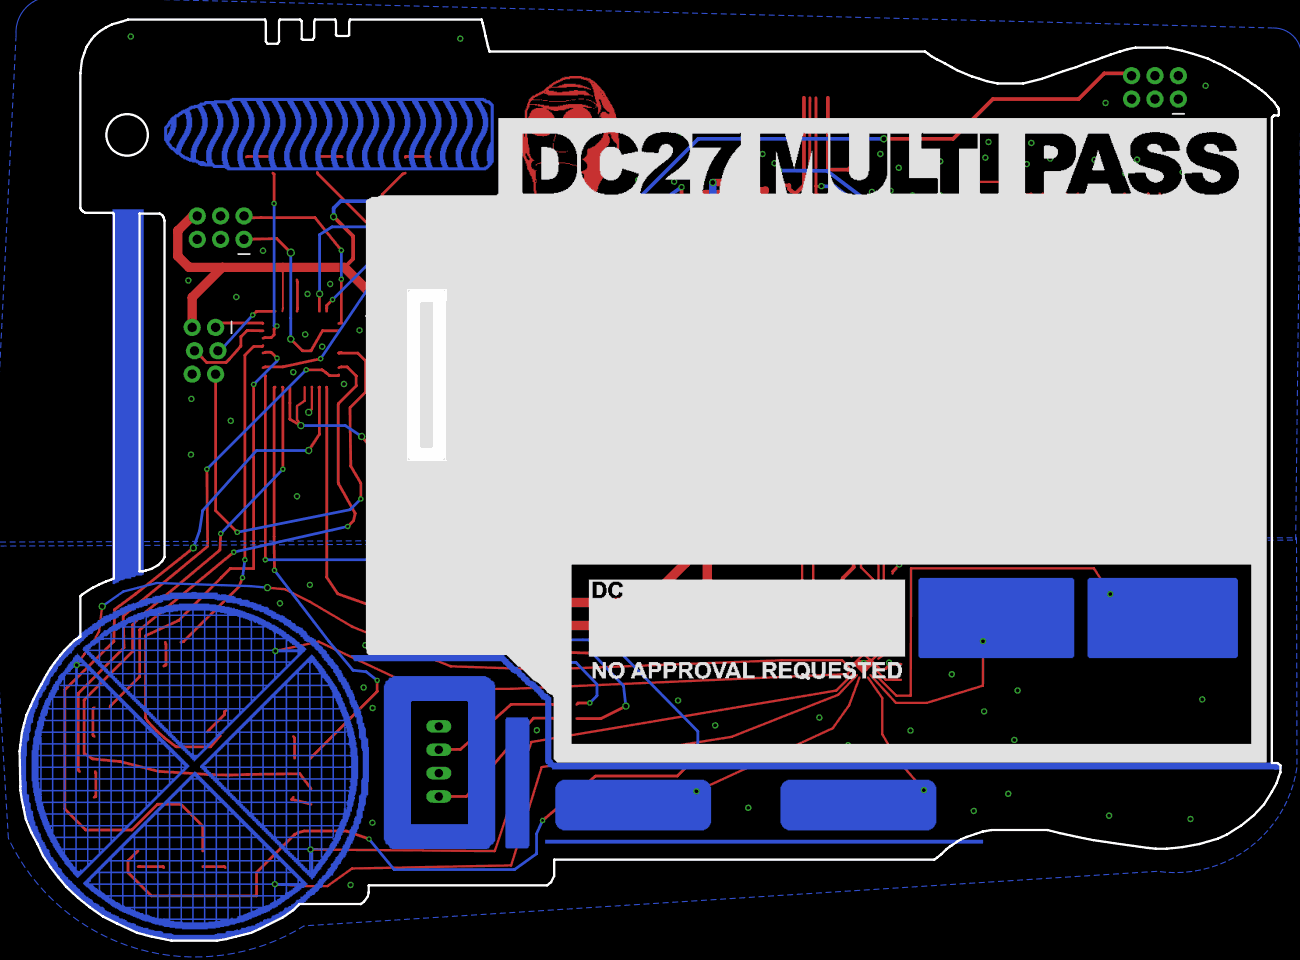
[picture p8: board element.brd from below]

Board: 2 copper layers, 137.0 x 100.1 mm, 208 parts (40 on the bottom side), 107 nets.

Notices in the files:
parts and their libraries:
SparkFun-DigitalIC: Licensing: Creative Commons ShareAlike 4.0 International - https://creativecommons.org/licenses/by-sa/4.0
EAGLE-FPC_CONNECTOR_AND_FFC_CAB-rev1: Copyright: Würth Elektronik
